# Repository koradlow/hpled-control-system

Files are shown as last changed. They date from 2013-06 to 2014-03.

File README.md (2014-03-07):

HPLED-Control System
====================
The goal of this project is to provide a Web-enabled system for driving 
and controlling high-power LEDs (HPLEDS). 

The project evolved into a distributed embedded system, consisting of 
custom controller boards for HPLEDs, a Linux based coordinator for 
controlling multiple controller boards (Raspberry Pi), a dynamic 
RESTful web-API and a responsive Js web user interface.

The project consists of several subprojects:
* HPLED-Driver PCB: Eagle files for the PCB design can be found in the 
*schematics* folder
* HPLED-Driver Software: The software running on the PCBs is available in
the *rgb-pcb* folder
* Web-interface: The jQuery mobile & flask based web interface can be 
found in the folder *web_interface*
* Coordinator control software: The software for interacting with the 
HPLED-Driver PCB can be found in the *i2c_raspberry* folder

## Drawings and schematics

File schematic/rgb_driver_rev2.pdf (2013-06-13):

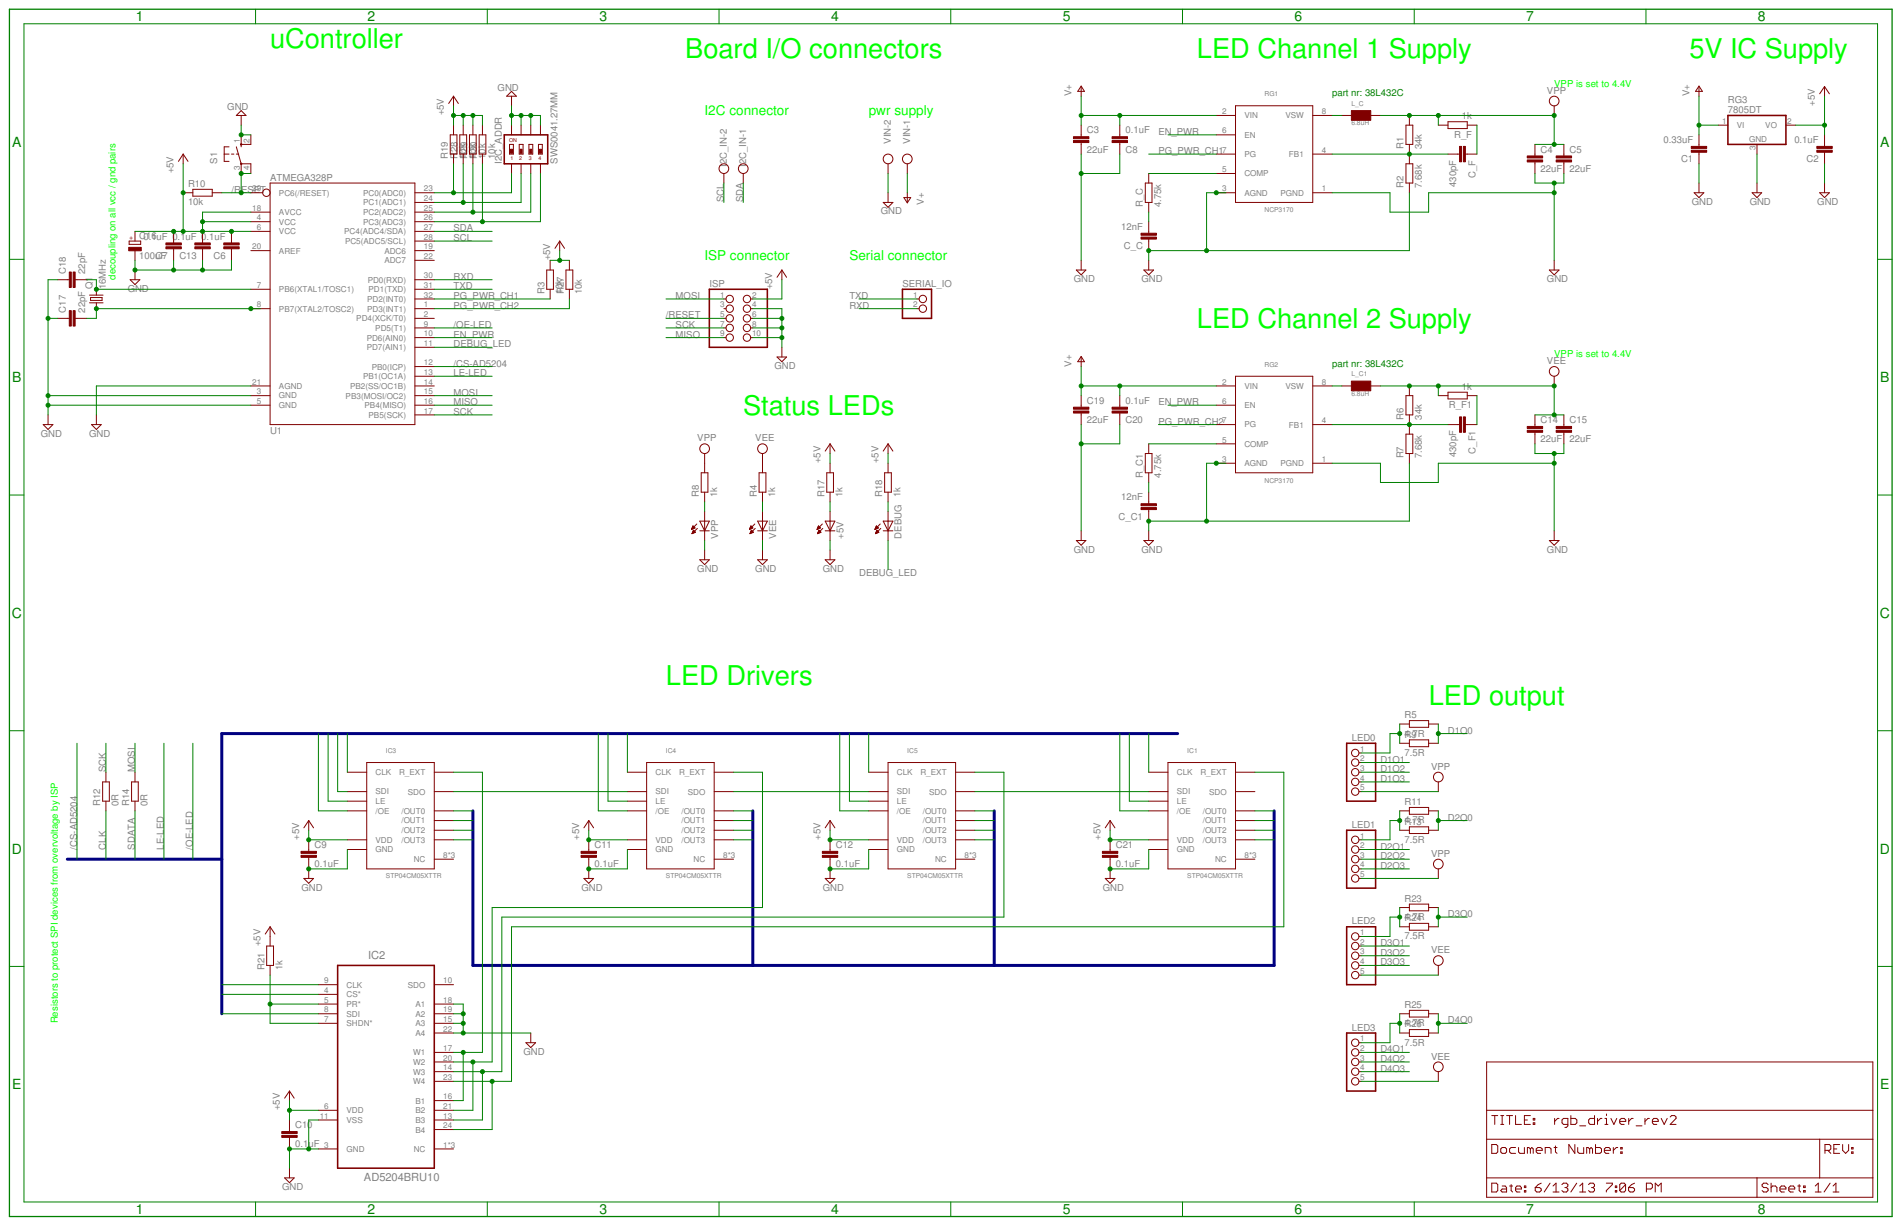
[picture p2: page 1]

VPP is set to 4.4V
VPP

decoupling on all vcc / gnd pairs

VPP is set to 4.4V LED Channel 2 Supply

Resistors to protect SPI devices from overvoltage by ISP

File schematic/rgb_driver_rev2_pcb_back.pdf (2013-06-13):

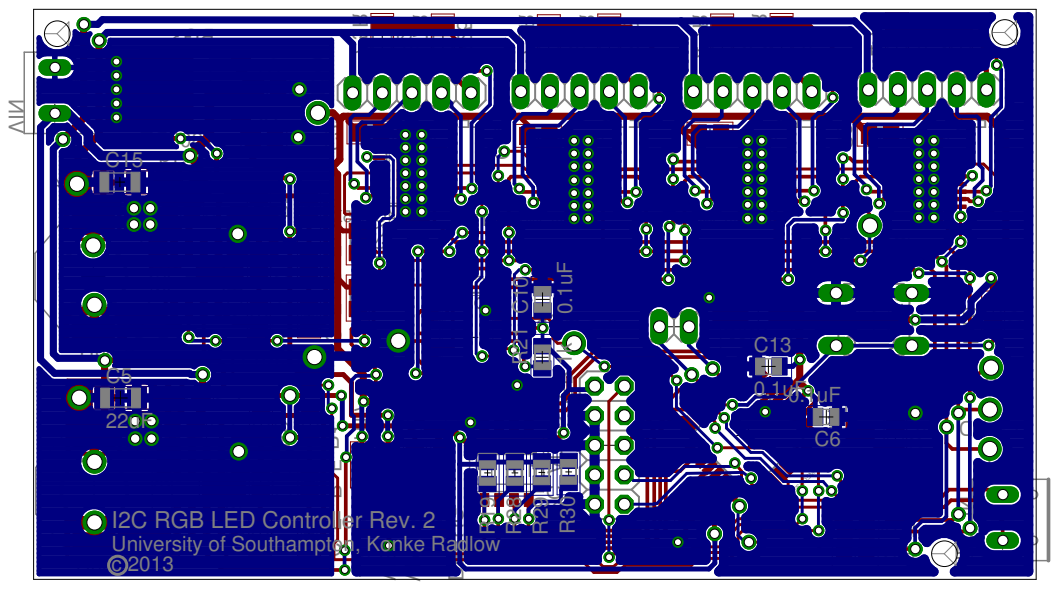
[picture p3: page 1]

I2C RGB LED Controller Rev. 2 University of Southampton, Konke Radlow

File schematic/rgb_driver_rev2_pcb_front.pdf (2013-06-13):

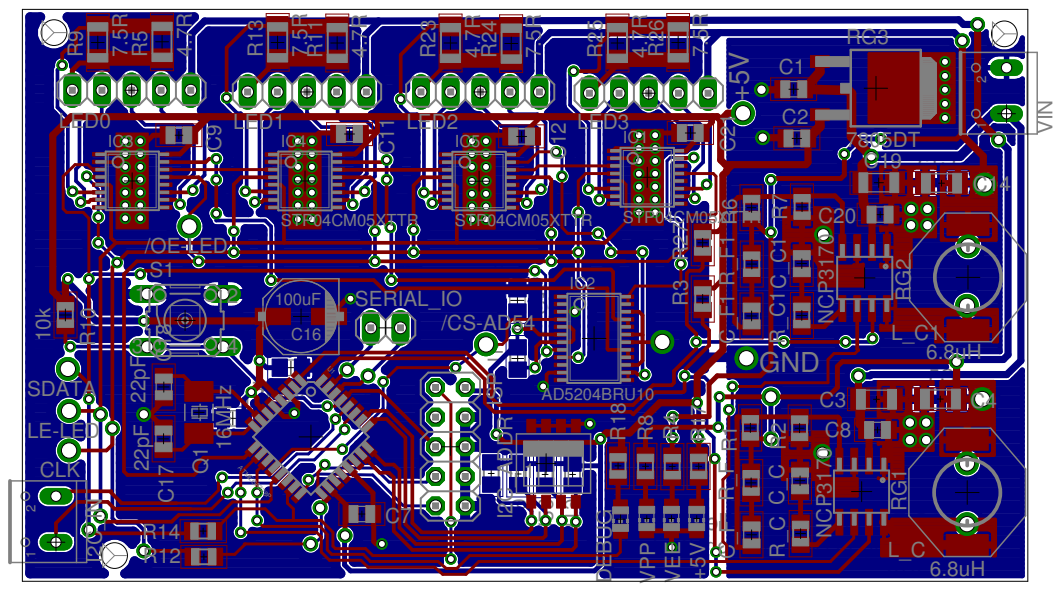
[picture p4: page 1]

STP04CM05XTTR | STP04CM05XTTR

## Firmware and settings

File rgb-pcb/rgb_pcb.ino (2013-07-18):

#include <SPI.h>
#include <EEPROM.h>
#include <TimerOne.h>
#include <util/atomic.h>

extern "C" {
	#include <twislave_sm.h>
}

/*
 * Macros to set and clear bits
 */
#ifndef cbi
#define cbi(sfr, bit) (_SFR_BYTE(sfr) &= ~_BV(bit))
#endif
#ifndef sbi
#define sbi(sfr, bit) (_SFR_BYTE(sfr) |= _BV(bit))
#endif 

/*
 * Module constants and pin definitions
 */
#define PWM_LEVELS 32
#define PWM_STEP 256/PWM_LEVELS
#define LED_COUNT 4

/* define the offsets in the receive and transmit buffers for I2C (TWI) */
#define RX_RGB_LED 0
#define RX_CURRENT_LIMIT 16
#define RX_CURRENT_UPDATE 20
#define RX_CURRENT_BRIGHTNESS 21
#define RX_MESSAGE_CLEAR 25
#define TX_CURRENT_LIMIT 0
#define TX_MESSAGE_CNT 4
#define TX_MESSAGE 5
#define EEPROM_CURRENT 0

/* the latch / /CS pin has to be on portB to allow setting it's value with 
 * direct port access to improve the execution speed */
const int ledLatchPin = 9;
const int ledLatchPinPORTB = ledLatchPin - 8;
const int potiCsPin = 8;
const int potiCsPinPORTB = potiCsPin - 8;
const int enPwr = 6;
const int debugLed = 7;
const int ledOEPin = 5;
const int ssPin = 10;

/* 
 * Data structures 
 */
struct RGB_LED {
	uint8_t r;
	uint8_t g_1;
	uint8_t g_2;
	uint8_t b;
};

struct RGB_State {
	struct RGB_LED led[LED_COUNT];
	uint8_t current_limit[LED_COUNT];
	uint8_t dummy_byte;	// for correct memory mapping to rx buffer
	uint8_t brightness;
};

/*
 * Global variables
 */
volatile struct RGB_State rgb_state;
static volatile uint16_t soft_pwm;
static volatile uint8_t ticker = 0;
static volatile bool twi_rx_event;

/*
 * Helper functions
 */
/* the Poti has a range of 10kOhm divided in 255 discrete steps,
 * set Terminal Bx to gnd and measure resistance between Wx and gnd.
 * Global interrupts are disabled during execution of this function to
 * prevent intervention with other functions that make use of SPI
 * --> value 0 => ~10k Ohm
 * --> value 215 => ~1.5k Ohm 
 * --> value 251 => ~200 Ohm */
void setPotiValue(byte channel, byte value) {
	cli();
	bitClear(PORTB, potiCsPinPORTB);
	SPI.transfer(channel);
	SPI.transfer(value);
	bitSet(PORTB, potiCsPinPORTB);
	sei();
}

/* reads the lower 4 bits of the I2C slave address for this board set with
 * a 4-way DIP switch */
uint8_t read_i2c_slave_address_dip(void) {
	uint8_t i2c_addr = digitalRead(A0) | digitalRead(A1) << 1 | 
			digitalRead(A2) << 2 | digitalRead(A3) << 3;
	return i2c_addr;
}

/* reads the current limit values from the EEPROM and updates the values
 * in the local buffers */
void read_current_limit_eeprom(void) {
	for(uint8_t channel = 0; channel < LED_COUNT; channel++) {
		rgb_state.current_limit[channel] = EEPROM.read(EEPROM_CURRENT+channel);
	}
	memcpy((void*)&rxbuffer[RX_CURRENT_LIMIT], (void*)&rgb_state.current_limit[0], LED_COUNT);
	memcpy((void*)&txbuffer[TX_CURRENT_LIMIT], (void*)&rgb_state.current_limit[0], LED_COUNT);
	rxbuffer[RX_CURRENT_UPDATE] = true;
}

/* writes the current limit to the EEPROM */
void write_current_limit_eeprom(void) {
	for(uint8_t channel = 0; channel < LED_COUNT; channel++)
		EEPROM.write(EEPROM_CURRENT+channel, rgb_state.current_limit[channel]);
}

void set_current_limit() {
	for (uint8_t channel = 0; channel < LED_COUNT; channel++) 
		setPotiValue(channel, rgb_state.current_limit[channel]);
}

void sendByte(byte value) {
	bitSet(PORTB,ledLatchPinPORTB);
	SPI.transfer(value);
	bitClear(PORTB,ledLatchPinPORTB);
}

void sendBytes(uint16_t value) {
	SPI.transfer((value >> 8));
	SPI.transfer(value);
	bitSet(PORTB,ledLatchPinPORTB);
	bitClear(PORTB,ledLatchPinPORTB);
}

/* set flag to notify main loop about TWI rxbuffer update */
void twi_sl_rcv_cb(uint8_t addr, uint8_t length) {
	twi_rx_event = true;
}

/* calculate the bitfield for 8 PWM channels */
uint8_t pwm_bitfield(uint8_t idx, uint8_t current_val) {
	static uint8_t bitfield = 0;
	static uint8_t soft_pwm_idx = 0;
	static uint8_t rgb[4];
	for(uint8_t led = idx; led < idx+2; led++) {
		rgb[0] = rgb_state.led[led].r;
		rgb[1] = rgb_state.led[led].g_1;
		rgb[2] = rgb_state.led[led].g_2;
		rgb[3] = rgb_state.led[led].b;
		for (uint8_t channel = 0; channel < 4; channel++) {
				if (current_val > 255-rgb[channel])
					bitfield |= _BV(soft_pwm_idx);
				++soft_pwm_idx;
			}
		}
		return bitfield;
}

/* calculate the soft pwm values, and output them via SPI
 * (periodic callback function for Timer1) */
void updatePWM() {
	/* update output at beginning of function to account for variable
	 * execution time of the function (lower jitter) */ 
	sendBytes(soft_pwm);

	/* if the soft pwm ticker / comperator overflows, reset the current
	 * soft-pwm values */
	if ( ++ticker >= PWM_LEVELS ){
		ticker = 0;
		soft_pwm = 0;
	}

	/* calculate the pwm values for the next iteration */
	uint8_t current_val = ticker * PWM_STEP;
	soft_pwm |= pwm_bitfield(0, current_val);
	soft_pwm |= pwm_bitfield(2, current_val) << 8;
}

void setup() {
	cli();
	/* configure & set the SS pins for SPI communication with slave ICs*/
	pinMode(ledLatchPin, OUTPUT);
	pinMode(potiCsPin, OUTPUT);
	pinMode(enPwr, OUTPUT);
	pinMode(debugLed, OUTPUT);
	pinMode(ledOEPin, OUTPUT);
	
	digitalWrite(ledLatchPin, LOW);
	digitalWrite(potiCsPin, HIGH);
	digitalWrite(enPwr, HIGH);
	
	/* Enable SPI output and configure non-default options.
	 * Both STP04CM05 and AD5204 IC support SPI in high speed mode
	 * 
	 * Important: with the first revision of the pcb the /SS pin has to 
	 * be set to output manually to prevent the SPI from entering slave mode */
	pinMode(ssPin, OUTPUT);
	SPI.begin();
	sbi(SPCR, SPI2X);

	/* read the current limit values from EEPROM to restore the old state */
	read_current_limit_eeprom();

	/* initialize Timer1 for periodic callback of soft pwm function (period in usecs) */
	Timer1.initialize( 400 ); 
	Timer1.attachInterrupt(updatePWM);

	/* initialize TWI (I2C) - it is configured to behave as an interrupt driven
	 * externally addressable read/write memory with globally accessible transmit
	 * and receive buffers (txbuffer, rxbuffer) */
	uint8_t i2c_sl_addr = 0x20 | read_i2c_slave_address_dip();
	// de-activate internal pullups for twi.
	digitalWrite(SDA, 0);
	digitalWrite(SCL, 0);
	init_twi_slave(i2c_sl_addr, false);
	register_sl_receive_cb(twi_sl_rcv_cb);
	sei();
}

void loop() {
	/* update the local rgb state by copying the values from the I2C receive
	* buffer, if the data was received */
	if (twi_rx_event) {
		memcpy((void*)&rgb_state, (void*)&rxbuffer[0], BUFFER_SIZE);
		twi_rx_event = false;
	}
	/* update the brightness for all LED drivers */
	analogWrite(ledOEPin, rgb_state.brightness);
	
	/* check if the current limit was updated */
	if (rxbuffer[RX_CURRENT_UPDATE] != 0x00) {
		set_current_limit();
		memcpy((void*)&txbuffer[TX_CURRENT_LIMIT], (void*)&rgb_state.current_limit[0], LED_COUNT);
		rxbuffer[RX_CURRENT_UPDATE] = false;
		write_current_limit_eeprom();
	}
	delay(25);
}
// x = (10k - R_pot) / 39

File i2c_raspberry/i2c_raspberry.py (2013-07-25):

#!/usr/bin/python
import decorator
import time
import sys, os, io, json
from random import randint
from pprint import pprint

import i2c as i2c

LED_CNT = 4
LED_CHANNELS = 4
RX_SIZE =  25
RX_RGB_LED = 0
RX_CURRENT_LIMIT = 16
RX_CURRENT_UPDATE = 20
RX_BRIGHTNESS = 21

def retry(howmany, *exception_types, **kwargs):
	timeout = kwargs.get('timeout', None) # seconds
	@decorator.decorator
	def try_it(func, *fargs, **fkwargs):
			for _ in range(howmany):
					try:
						return func(*fargs, **fkwargs)
					except exception_types as e:
						print("I/O Exception, retry %d" % _)
						exc_type, exc_obj, exc_tb = sys.exc_info()
						fname = os.path.split(exc_tb.tb_frame.f_code.co_filename)[1]
						print(exc_type, fname, exc_tb.tb_lineno)
						if timeout is not None: time.sleep(timeout)
	return try_it


class RgbLedSet(object):
	def __init__(self, name="undef"):
		self.leds = []
		self.name = name
		self.status = 'on'
	
	def set_name(self, new_name):
		self.name = new_name
		for led in self.leds:
			led.led_set = new_name
	
	def set_status(self, status):
		self.status = 'off' if status in ['off', 'OFF', 'Off'] else 'on'
		for led in self.leds:
			led.enabled = False if self.status == 'off' else True

	def add_led(self, led):
		led.led_set = self.name
		if led not in self.leds:
			self.leds.append(led)
	
	def remove_led(self, led):
		if led in self.leds:
			idx = self.leds.index(led)
			self.leds[idx].led_set = 'none'
			self.leds.remove(led)

	def get_leds(self):
		for led in self.leds:
			if led.led_set != self.name:
				self.leds.remove(led) 
		return self.leds

	def to_dict(self):
		led_list = []
		for led in self.get_leds():
			led_list.append(led.to_dict())
		led_set_dict = {
			'name': self.name,
			'leds': led_list,
			'status' : self.status
		}
		
		return led_set_dict


class RgbLed(object):
	def __init__(self, master_addr, channel, current_limit=245):
		self.current_limit = current_limit
		self.channels = [0, 0, 0, 0]
		self.current_limit_update = False
		self.master_addr = master_addr
		self.channel = channel
		self.led_set = 'none'
		self.enabled = True

	def __eq__(self, other):
		return self.master_addr == other.master_addr and self.channel == other.channel

	def __neq__(self, other):
		return not self == other

	def set_color(self, rgb_color):
		r = rgb_color.get('r', None)
		g = rgb_color.get('g', None)
		g1 = rgb_color.get('g1', None)
		g2 = rgb_color.get('g2', None)
		b = rgb_color.get('b', None)

		if r is not None: self.channels[0] = r
		if g is not None: self.channels[1] = self.channels[2] = g
		if g1 is not None: self.channels[1] = g1
		if g2 is not None: self.channels[2] = g2
		if b is not None: self.channels[3] = b
	
	def get_color(self):
		return {
			'r':self.channels[0], 
			'g':self.channels[1],
			'g2':self.channels[2],
			'b':self.channels[3],
		}

	def set_current_limit(self, current_limit):
		if current_limit is not self.current_limit:
			self.current_limit = int(current_limit)
			self.current_limit_update = True

	# to make it easy to use the API, the interface uses values in mA. These
	# values have to be converted into the values expected by the LED-Driver board.
	# The led driver board expects decimal values between 0 and 255 that 
	# are used to set the value of a digital resistor (AD5204) (0=10kOhm,255=45Ohm),
	# which is used to set the current limit of the LED-Drivers
	def convert_current_limit(self):
		r_ext = interpolate_resistor_value(self.current_limit)
		return calculate_digital_resistor_input(r_ext)
	
	def to_dict(self):
		led_dict = {}
		led_dict['channel'] = self.channel
		led_dict['controller'] = self.master_addr
		led_dict['current_limit'] = self.current_limit
		led_dict['color'] = self.get_color()
		led_dict['led_set'] = self.led_set
		
		return led_dict


class RgbController(object):
	def __init__(self, address, name, led_cnt = LED_CNT):
		self.i2c_address = address
		self.name = name
		self.brightness = 0
		self.i2c_buffer = bytearray(RX_SIZE)
		self.led_cnt = led_cnt
		self.leds = []
		self.create_leds()

	def create_leds(self):
		for idx in range(self.led_cnt):
			self.leds.append(RgbLed(self.i2c_address, idx))

	def get_led(self, index):
		return self.leds[index]
		
	def set_brightness(self, brightness):
		self.brightness = brightness
		self.i2c_buffer[RX_BRIGHTNESS] = brightness
	
	def update_i2c_buffer(self):
		for idx in range(len(self.leds)):
				led = self.leds[idx]
				self.i2c_buffer[idx*LED_CHANNELS] = int(led.channels[0] if led.enabled else 0)
				self.i2c_buffer[idx*LED_CHANNELS+1] = int(led.channels[1] if led.enabled else 0)
				self.i2c_buffer[idx*LED_CHANNELS+2] = int(led.channels[2] if led.enabled else 0)
				self.i2c_buffer[idx*LED_CHANNELS+3] = int(led.channels[3] if led.enabled else 0)
				self.i2c_buffer[RX_CURRENT_LIMIT+idx] = int(led.convert_current_limit())
				if (led.current_limit_update):
					self.i2c_buffer[RX_CURRENT_UPDATE] = 0x01
					led.current_limit_update = False;
				self.i2c_buffer[RX_BRIGHTNESS] = int(self.brightness)

	def get_state(self):
		return self.i2c_buffer
	
	def to_dict(self):
		leds = []
		for led  in self.leds:
			leds.append(led.to_dict())
		controller_dict = {
				'addr': self.i2c_address, 
				'name': self.name, 
				'brightness': self.brightness,
				'led_cnt': self.led_cnt,
				'leds': leds
			}

		return controller_dict
	
	@retry(2, IOError, timeout=0.05)
	def update_color(self):
		self.update_i2c_buffer()
		length = bytearray(1)
		length[0] = 16 + 1
		with i2c.I2CMaster() as bus:
			bus.transaction(
				i2c.writing_bytes(self.i2c_address, 0x00),
				i2c.writing(self.i2c_address, self.i2c_buffer[0:16] + length))

	@retry(2, IOError, timeout=0.05)
	def update_limits(self):
		self.update_i2c_buffer()
		length = bytearray(1)
		length[0] = 7 + 1
		with i2c.I2CMaster() as bus:
			bus.transaction(
				i2c.writing_bytes(self.i2c_address, 0x10),
				i2c.writing(self.i2c_address, self.i2c_buffer[16:23] + length))
		
	@retry(2, IOError, timeout=0.05)
	def update(self):
		self.update_i2c_buffer()
		length = bytearray(1)
		length[0] = 23 + 1
		with i2c.I2CMaster() as bus:
			bus.transaction(
				i2c.writing_bytes(self.i2c_address, 0x00),
				i2c.writing(self.i2c_address, self.i2c_buffer[0:23] + length))



@retry(2, IOError, timeout = 0.05)
def read(source, count):
	with i2c.I2CMaster() as bus:
		print("reading %d bytes from %02x" % (count, source))
		result = bus.transaction(
			i2c.writing_bytes(I2C_SLAVE_ADDRESS, source),
			i2c.reading(I2C_SLAVE_ADDRESS, count))

		return result[0]
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

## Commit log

2013-05-24 Initial transmit
    Status: Color and brightness control implemented & tested
    Behavior: all 4 leds shift through a color pattern
2013-05-24 setting pin mode of /SS pin in user program instead of SPI library
2013-05-25 Integrated twislave library Added "set_brightness" and "set_current_limit" based on rxbuffer
    Status: led values can be defined, brightness and current limit can be controlled
2013-05-25 Added read/write current limit from/to EEPROM
    current limit is read during initialization, value is provided in
    the transmit buffer and written to the LED drivers. When the current
    value is updated over I2C the new values are stored in the EEPROM
2013-05-25 added i2c python testcode for raspberry
2013-05-25 i2c-raspberry: split testcode into functions
2013-05-28 i2c-raspberry: added automatic retry when an I2C operation fails
2013-05-28 twislave_sm: library rewritten to improve speed and stability
    [twislave_sm.c]
2013-05-29 rgb_pcb: added feature - I2C address is set by DIP switch
2013-05-29 Implementing variable frequency soft pwm using Timer0
2013-06-03 Modified memory mapping and added very simple error protection for faulty I2C messages
    [rgb_pcb.ino, twislave_sm.c]
2013-06-03 i2c-raspberry: adopted to new memory map & I2C protocol changes, created class representation for rgb-driver modules
2013-06-05 i2c-raspberry: new class structure to represent and modify hardware state
2013-06-05 i2c-raspberry: setting the current_update flag in rx_buffer if value was updated
2013-06-13 Add schematics of rgb-driver hardware (Rev. 2)
    [rgb_driver_rev2.brd, rgb_driver_rev2.sch]
2013-06-18 web_interface: switch to jQuery mobile for UI, requesting data via AJAX
2013-06-19 web-interface: dynamically creating lists of controllers and led sets reported by RESTApi
2013-06-21 web-interface: new page for creating LED-Sets
2013-06-24 web-interface: creating and editing LED-Sets (synced backend)
2013-06-25 web-interface & i2c_mock: LED-Sets can be deleted, existing LED-Sets show up in the side panel
2013-06-25 web-interface: LED-Sets can be controlled via web-interface
2013-06-26 quick2wire I2C: fix compability with python < 3, make standalone
    [i2c.py]
2013-07-03 web-interface & coordinator: current limit defined in mA, transformation in coordinator
2013-07-03 conversion into digital resistor input value range perfomed on the fly during I2C update
2013-07-04 coordinator: LED-Sets are stored in a file an restored at program start
2013-07-04 web-interface, coordinator: LED-Sets can be switched off and on
2013-07-11 coordinator: scan I2C bus for devices at startup
2013-07-11 rgb_pcb: adopt to new pcb revision and change shift out function
2013-07-12 coordinator: change addressing of led driver IC channels
2013-07-18 web-interface & coordinator: added unit test for web-API, fixed bugs in coordinator
    [i2c_raspberry.py]
2013-07-18 i2c_raspberry: added program for testing I2C interface
2013-07-24 web-interface: added option to treat all LEDs of a Set as one
2013-07-25 Web-frontend: added possibility to change colors of LED-Sets periodically (mood light)
